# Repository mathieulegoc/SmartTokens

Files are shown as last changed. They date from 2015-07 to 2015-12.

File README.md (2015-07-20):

# SmartTokens
SmartTokens are small-sized tangible tokens that can sense multiple types of motion, multiple types of touch/grip, and send input events wirelessly as state-machine transitions. By providing an open platform for embedding basic sensing capabilities within small form-factors, SmartTokens extend the design space of tangible user interfaces. Here is all the material required to build and use SmartTokens, from PCB production files to code.

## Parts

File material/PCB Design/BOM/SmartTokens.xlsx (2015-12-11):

Designator | Quantity | Description | Supplier 1 | Supplier Part Number 1 | Supplier 2 | Supplier Part Number 2
A1 | 1 | JOHANSON TECHNOLOGY 2450AT18A100E ANTENNA, CERAMIC, 2.45GHZ | Digi-Key | 712-1005-1-ND | Farnell | 1885496
C1, C7 | 2 | 47pF 0402 NP0 50V ±5% | Digi-Key | 445-1243-1-ND | Farnell | 8819670
C2 | 1 | 10uF 0603 X5R 6.3V ±20% | Digi-Key | 478-5318-1-ND | Farnell | 1833804
C3, C4, C5, C8, C9, C10, C14, C16, C18 | 9 | 100nF 0402 X7R 16V ±10% | Digi-Key | 399-3521-1-ND | Farnell | 1288252
C6, C19 | 2 | 10nF 0402 X7R 25V ±5% | Digi-Key | 399-1279-1-ND | Farnell | 1692285
C11, C12 | 2 | 15pF 0402 NP0 50V ±5% | Digi-Key | 399-1014-1-ND | Farnell | 1414577
C13, C15 | 2 | 1uF 0603 X5R 10V ±10% | Digi-Key | 478-1251-1-ND | Farnell | 1759399
C17 | 1 | 10uF 0603 TANTALUM 10V ±20% | Digi-Key | 478-9527-1-ND | Farnell | 2408423
L1 | 1 | MURATA - LQP15MN3N9B02D - 3.9NH ±0.1NH 0402 | Digi-Key | 490-1131-1-ND
L2 | 1 | MURATA - LQP15MN5N1B02D - 5.1NH ±0.1NH 0402 | Digi-Key | 490-6758-1-ND
R1 | 1 | 43K 0402 1/16W ±1% | Digi-Key | 541-43.0KLCT-ND | Farnell | 1358086
R2, R4, R6, R8, R9, R10, R11, R12 | 8 | 10K 0402 1/16W ±1% | Digi-Key | 541-10.0KLCT-ND | Farnell | 2072517
R5 | 1 | 100K 0402 1/16W ±1% | Digi-Key | 541-100KLCT-ND | Farnell | 2072519
U1 | 1 | NXP JN5168 IEEE802.15.4 Wireless Microcontroller | Digi-Key | 568-10145-1-ND | Farnell | 2341782
U2 | 1 | STMicroelectronics 150 mA ultra low quiescent current linear voltage regulator | Digi-Key | 497-10530-1-ND | Farnell | 2311337
U4 | 1 | Atmel AT42QT1070 Seven-channel QTouch® Touch Sensor IC | Digi-Key | AT42QT1070-MMHCT-ND
U5 | 1 | STMicroelectronics LSM6DS0 iNEMO inertial module | Digi-Key | 497-14855-1-ND | Farnell | 2462797
Y1 | 1 | EPSON - TSX-3225, 32MHZ, 10PPM, 9PF - CRYSTAL, TSX-3225, 32MHZ, 10PPM, 9PF |  |  | Farnell | 1712845

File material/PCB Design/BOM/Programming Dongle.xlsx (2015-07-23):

Designator | Quantity | Comment | Description | Supplier 1 | Supplier Part Number 1
C1 | 1 | 10uF 0603 X5R 6.3V AVX | AVX - 06036D106MAT2A - 0603 X5R 6.3V 10UF | Farnell | 1833804
C2 | 1 | 1uF 0603 X5R 10V MULTICOMP | MULTICOMP - MC0603X105K100CT - MLCC 0603 X5R 10V 1UF | Farnell | 1759399
C3, C4, C5, C7 | 4 | 100nF 0402 X7R 16V ±10% | 100nF 0402 X7R 16V ±10% | Farnell | 1288252
C6 | 1 | 4.7uF 0603 X5R 10V KEMET | KEMET - C0603C475K8PACTU - CONDENSATEUR 4.7UF 10V X5R 0603 | Farnell | 1572625
C8 | 1 | 10nF 0402 X7R 25V KEMET | KEMET - C0402C103J3RACTU - MLCC 0402 25V 0.01UF | Farnell | 1692285
C9, C10 | 2 | 47pF 0402 NP0 50V MURATA | MURATA - GRM1555C1H470JZ01D - 0402 47PF 50V | Farnell | 8819670
D1 | 1 | OVS-0604 | MULTICOMP - OVS-0604 - LED, 0603, GREEN, 300MCD, 520NM | Farnell | 1716771
D2 | 1 | RGB LED PLCC | MULTICOMP - 703-1028 - LED RGB 3528 PLCC | Farnell | 2112143
D3, D4 | 2 | Schottky barrier single diode | NXP - 1PS76SB10 | Farnell | 1081179
FE1 | 1 | MURATA - BLM18PG471SN1D | Ferrite Bead (470R ~ 100MHz) | Farnell | 1515745
J1 | 1 | MICRO USB B | MOLEX - 47346-0001 - FEMALE MICRO USB B BOTTOM MOUNT | Farnell | 1568026
P1 | 1 | FTSH-104-04-F-DH | Samtec FTSH 4x2 .050" Horizontal SMD
R1 | 1 | 180R 0402 1% VISHAY | VISHAY DRALORIC - CRCW0402180RFKED - 0402 180R 1% | Farnell | 2140698
R2, R3 | 2 | 180R 0402 1/16W ±1% | 180R 0402 1/16W ±1% | Farnell | 2140698
U1 | 1 | ADP3333ARMZ-3.3-R7 | High Accuracy Ultralow IQ, 300 mA, anyCAP Low Dropout Regulator, 2.6 to 12 V Vin, 3.3 V Vout, Industrial, 8-pin SOP (RM-8), Reel | Digi-Key | ADP3333ARMZ-3.3-R7TR-ND
U2 | 1 | FT232RL | USB UART Asynchronous Serial Data Transfer Chip, SSOP-28, Tape and Reel | Farnell | 1146032

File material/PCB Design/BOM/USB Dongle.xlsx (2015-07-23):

Designator | Quantity | Comment | Description | Supplier 1 | Supplier Part Number 1
A1 | 1 | 2450AT18A100 | JOHANSON TECHNOLOGY 2450AT18A100E ANTENNA, CERAMIC, 2.45GHZ | Farnell | 1885496
C1 | 1 | 10uF 0603 X5R 6.3V AVX | AVX - 06036D106MAT2A - 0603 X5R 6.3V 10UF | Farnell | 1833804
C2, C3, C5, C6, C13, C14, C15, C18, C19, C20 | 10 | 100nF 0402 X7R 16V ±10% | 100nF 0402 X7R 16V ±10% | Farnell | 1288252
C4 | 1 | 1uF 0603 X5R 10V MULTICOMP | MULTICOMP - MC0603X105K100CT - MLCC 0603 X5R 10V 1UF | Farnell | 1759399
C7 | 1 | 4.7uF 0603 X5R 10V KEMET | KEMET - C0603C475K8PACTU - CONDENSATEUR 4.7UF 10V X5R 0603 | Farnell | 1572625
C8 | 1 | 10nF 0402 X7R 25V KEMET | KEMET - C0402C103J3RACTU - MLCC 0402 25V 0.01UF | Farnell | 1692285
C9, C10 | 2 | 47pF 0402 NP0 50V MURATA | MURATA - GRM1555C1H470JZ01D - 0402 47PF 50V | Farnell | 8819670
C11, C17 | 2 | 47pF 0402 NP0 50V ±5% | 47pF 0402 NP0 50V ±5% | Farnell | 8819670
C12 | 1 | 10uF 0603 X5R 6.3V ±20% | 10uF 0603 X5R 6.3V ±20% | Farnell | 1833804
C16 | 1 | 10nF | 10nF 0402 X7R 25V ±5% | Farnell | 1692285
C21, C22 | 2 | 15pF 0402 NP0 50V ±5% | 15pF 0402 NP0 50V ±5% | Farnell | 1414577
D1 | 1 | OVS-0604 | MULTICOMP - OVS-0604 - LED, 0603, GREEN, 300MCD, 520NM | Farnell | 1716771
D2 | 1 | RGB LED PLCC | MULTICOMP - 703-1028 - LED RGB 3528 PLCC | Farnell | 2112143
D3 | 1 | OVS-0603 | MULTICOMP - OVS-0603 - LED 0603 SUPER BRIGHT BLUE | Farnell | 1716770
D4, D5 | 2 | Schottky barrier single diode | NXP - 1PS76SB10 | Farnell | 1081179
FE1 | 1 | MURATA - BLM18PG471SN1D | Ferrite Bead (470R ~ 100MHz) | Farnell | 1515745
J1 | 1 | MICRO USB B | MOLEX - 47346-0001 - FEMALE MICRO USB B BOTTOM MOUNT | Farnell | 1568026
L1 | 1 | 3.9NH 0402 MURATA | MURATA - LQP15MN3N9B02D - 3.9NH ±0.1NH 0402 | Digi-Key | 490-1131-1-ND
L2 | 1 | 5.1NH 0402 MURATA | MURATA - LQP15MN5N1B02D - 5.1NH ±0.1NH 0402 | Digi-Key | 490-6758-1-ND
R1 | 1 | 180R 0402 1% VISHAY | VISHAY DRALORIC - CRCW0402180RFKED - 0402 180R 1% | Farnell | 2140698
R2, R3, R4 | 3 | 180R 0402 1/16W ±1% | 180R 0402 1/16W ±1% | Farnell | 2140698
R5 | 1 | 43K 0402 1/16W ±1% | 43K 0402 1/16W ±1% | Farnell | 1358086
U1 | 1 | ADP3333ARMZ-3.3-R7 | High Accuracy Ultralow IQ, 300 mA, anyCAP Low Dropout Regulator, 2.6 to 12 V Vin, 3.3 V Vout, Industrial, 8-pin SOP (RM-8), Reel | Digi-Key | ADP3333ARMZ-3.3-R7TR-ND
U2 | 1 | FT232RL | USB UART Asynchronous Serial Data Transfer Chip, SSOP-28, Tape and Reel | Farnell | 1146032
U3 | 1 | JN516X | IEEE802.15.4 Wireless Microcontroller | Farnell | 2341782
Y1 | 1 | TSX-3225 | EPSON - TSX-3225, 32MHZ, 10PPM, 9PF - CRYSTAL, TSX-3225, 32MHZ, 10PPM, 9PF | Farnell | 1712845

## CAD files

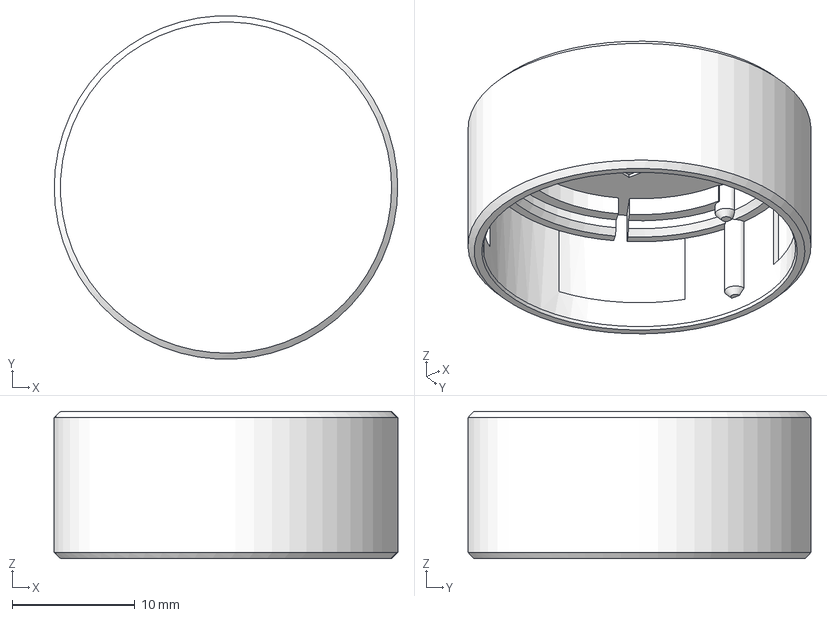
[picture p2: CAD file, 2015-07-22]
material/Shell Design/Step Files/top.stp
28.0 x 28.0 x 12.0 mm

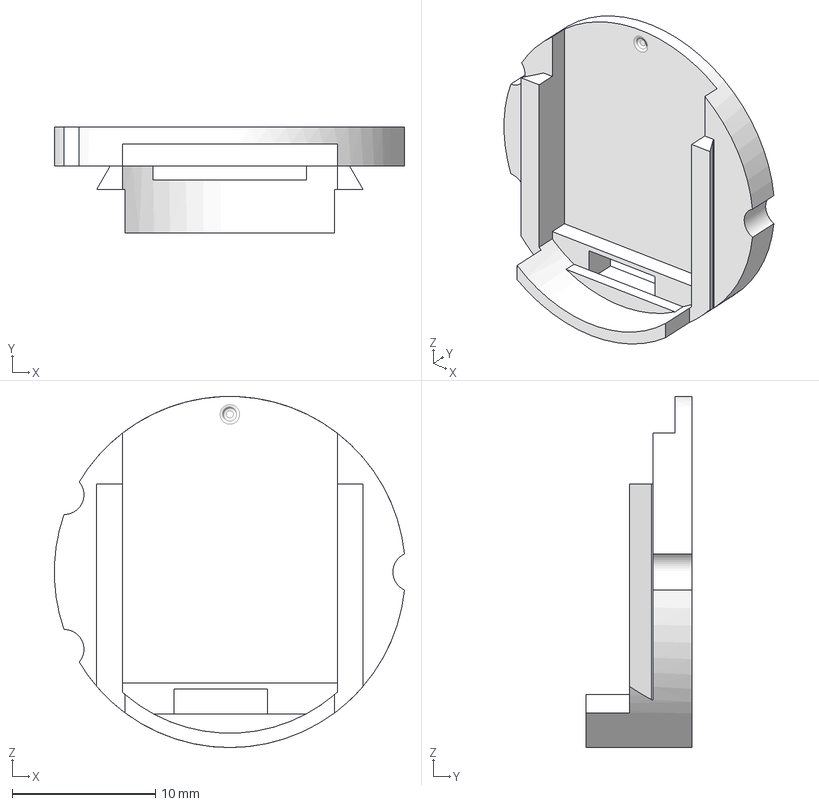
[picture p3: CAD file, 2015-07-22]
material/Shell Design/Step Files/bottom2_2.stp
24.4 x 7.38 x 24.5 mm

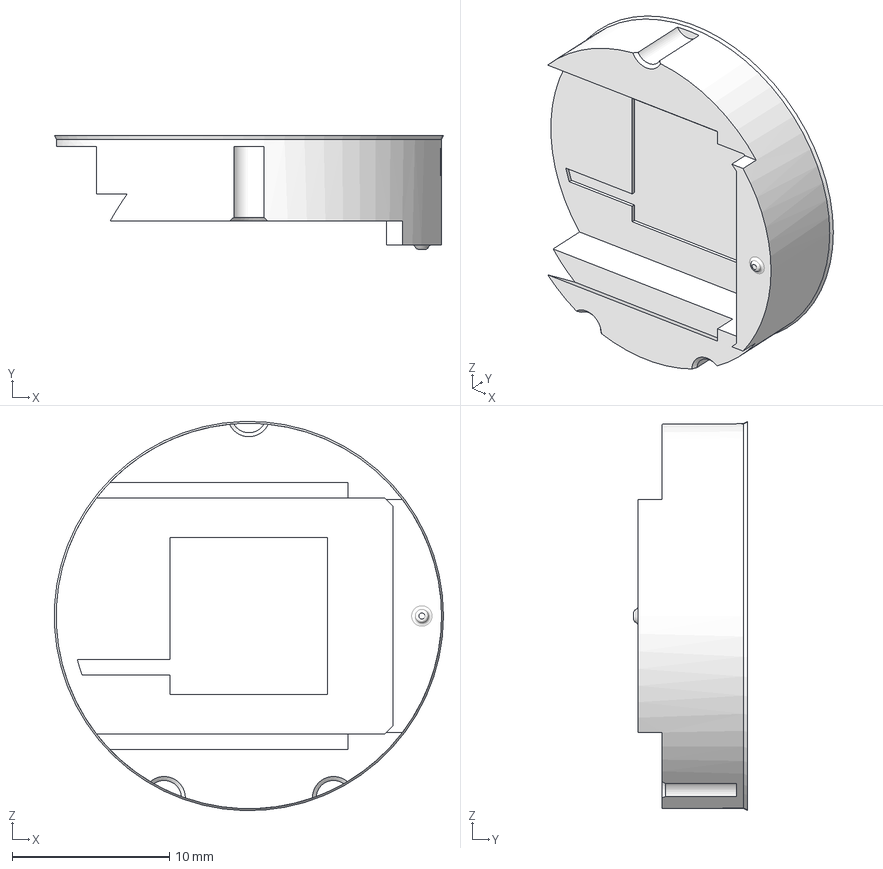
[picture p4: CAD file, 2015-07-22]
material/Shell Design/Step Files/bottom1_2.stp
24.7 x 7.25 x 24.7 mm

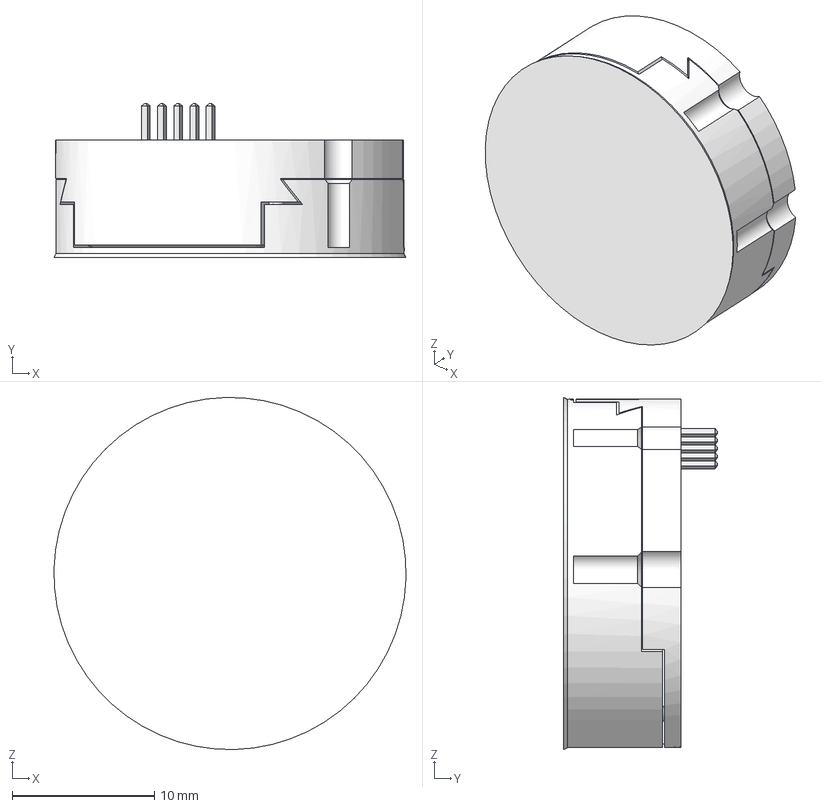
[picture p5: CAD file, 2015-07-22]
material/Shell Design/Step Files/battery_block.stp
24.7 x 10.8 x 24.7 mm
battery
bottom2_2
bottom1_2
battery_connector

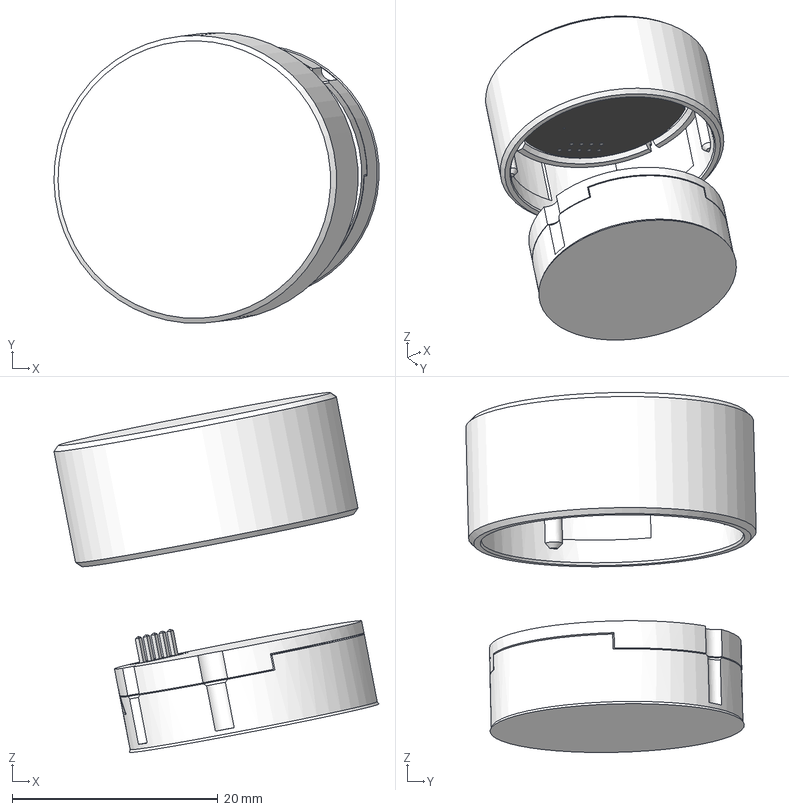
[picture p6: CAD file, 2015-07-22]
material/Shell Design/Step Files/smart_token.stp
31.6 x 28.2 x 35.0 mm
top
pcb
battery
bottom2_2
bottom1_2
battery_connector

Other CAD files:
material/Shell Design/Inventor Files/battery.ipt
material/Shell Design/Inventor Files/battery_block.iam
material/Shell Design/Inventor Files/battery_connector.ipt
material/Shell Design/Inventor Files/bottom1_2.ipt
material/Shell Design/Inventor Files/bottom2_2.ipt
material/Shell Design/Inventor Files/pcb.ipt
material/Shell Design/Inventor Files/smart_token.iam
material/Shell Design/Inventor Files/top.ipt
material/Shell Design/STL files/bottom1_2.stl
material/Shell Design/STL files/bottom2_2.stl
material/Shell Design/STL files/top.stl

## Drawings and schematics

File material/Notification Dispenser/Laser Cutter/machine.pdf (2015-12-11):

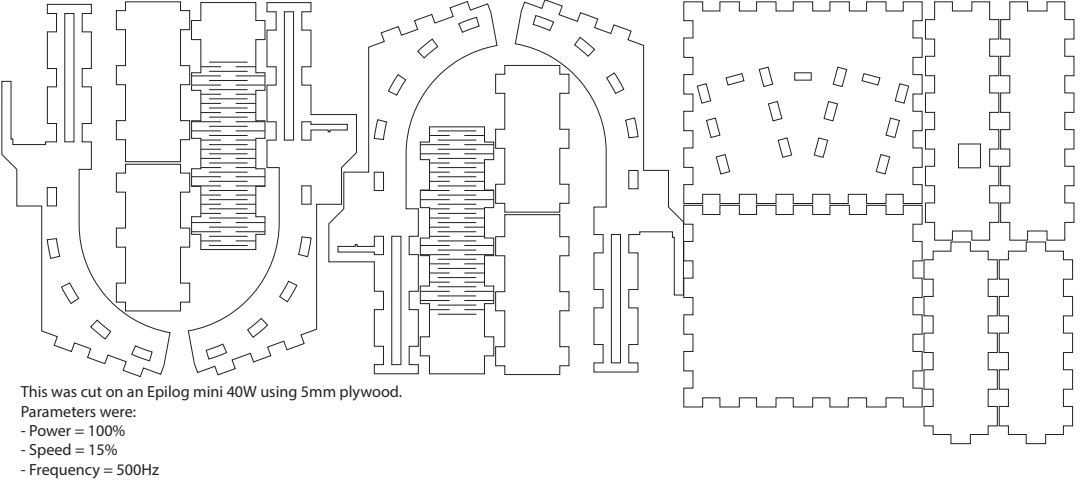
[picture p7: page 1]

This was cut on an Epilog mini 40W using 5mm plywood.
Parameters were:
- Power = 100%
- Speed = 15%
- Frequency = 500Hz

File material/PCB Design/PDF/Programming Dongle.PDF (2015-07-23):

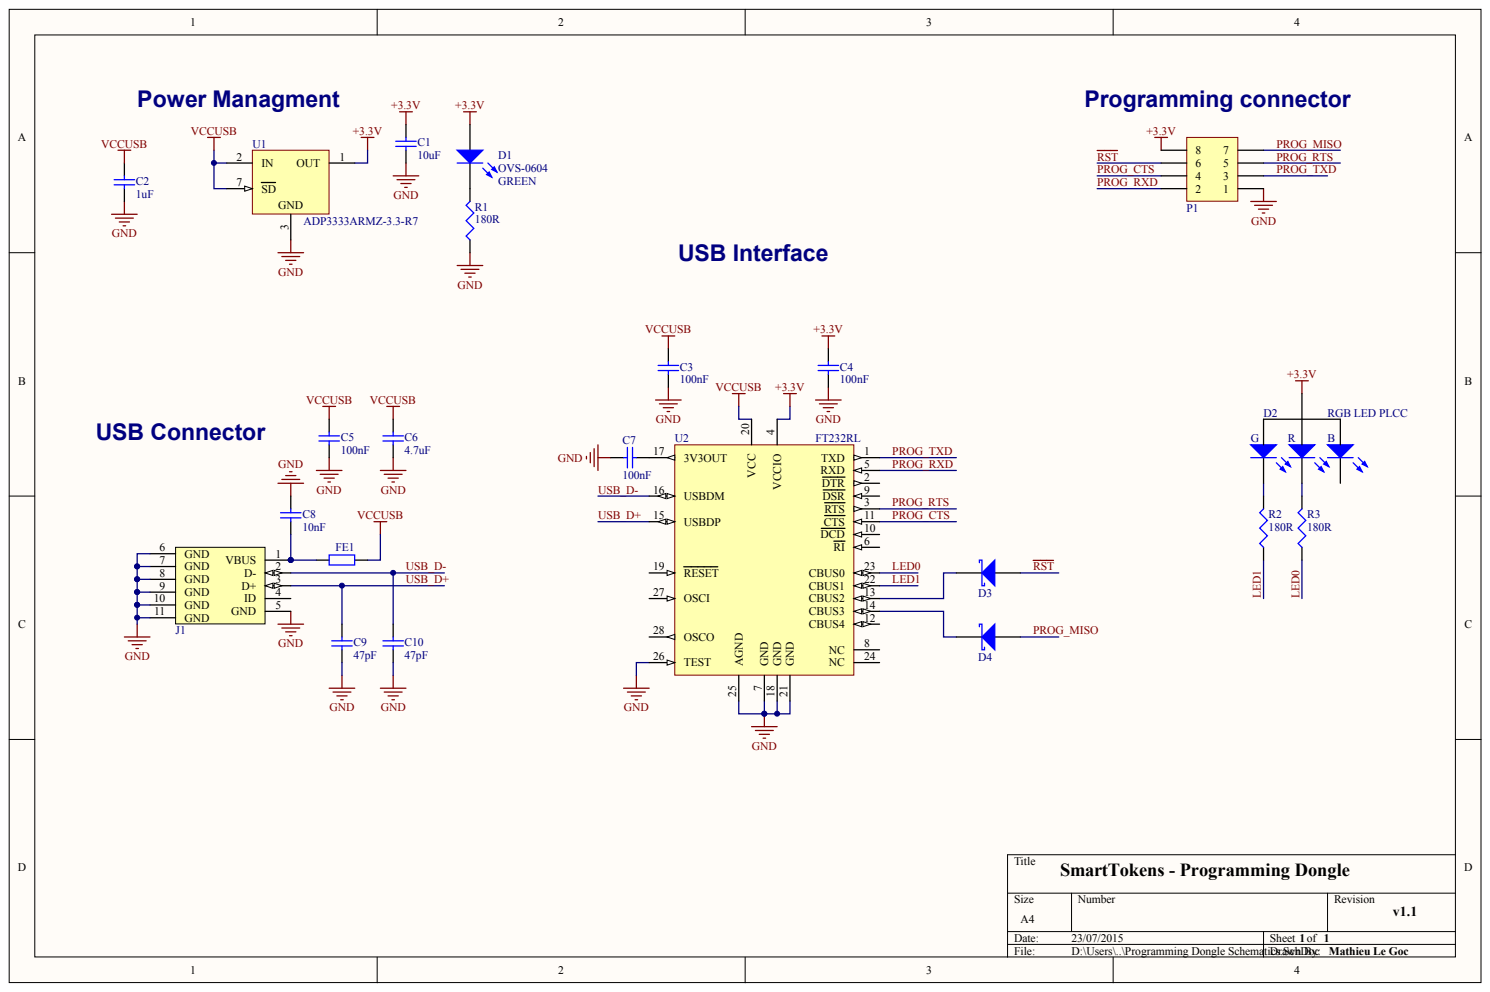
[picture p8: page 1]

OSCI 27 | LED1

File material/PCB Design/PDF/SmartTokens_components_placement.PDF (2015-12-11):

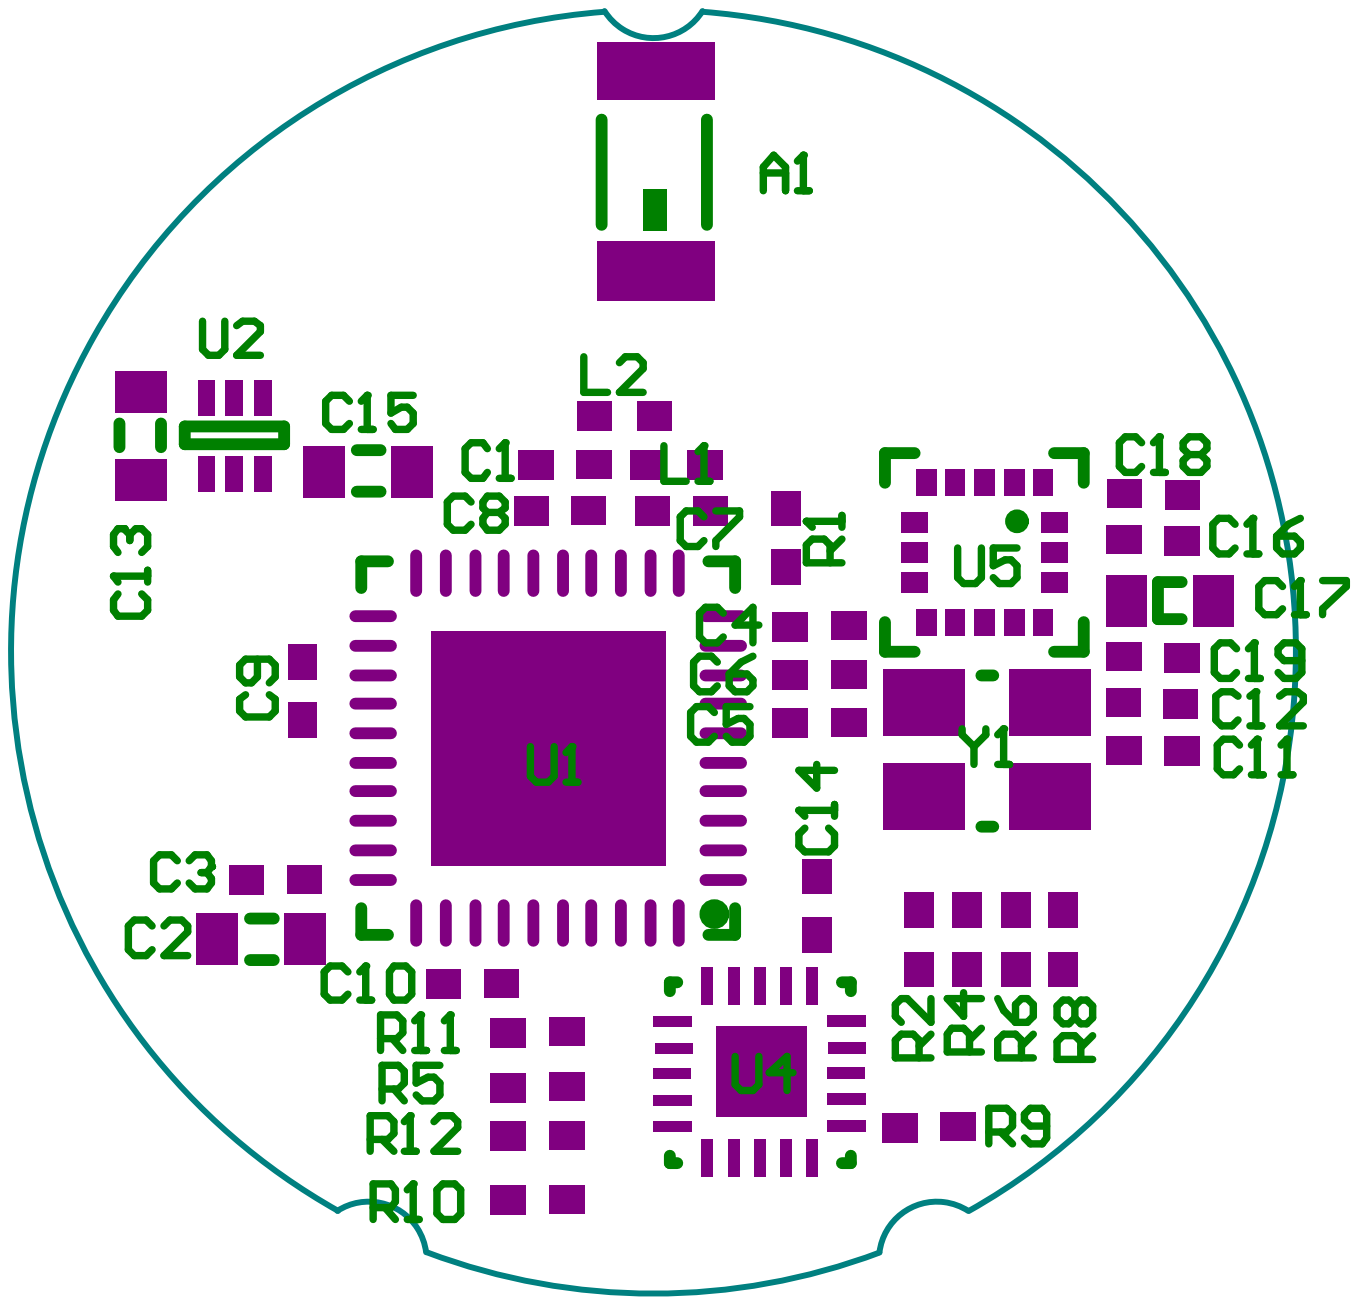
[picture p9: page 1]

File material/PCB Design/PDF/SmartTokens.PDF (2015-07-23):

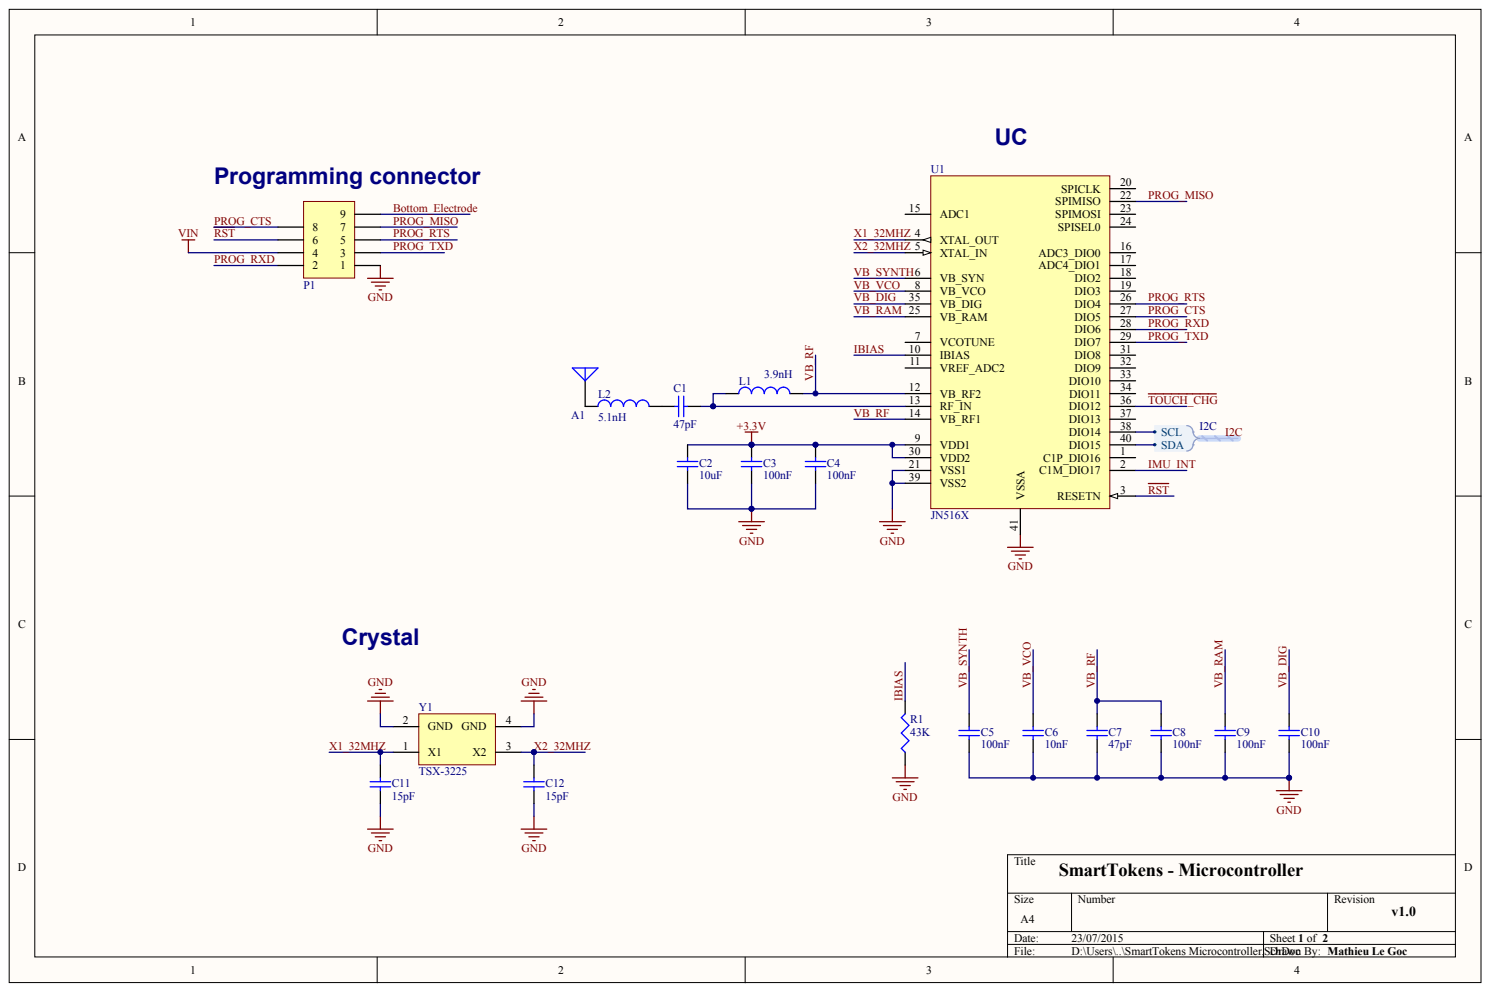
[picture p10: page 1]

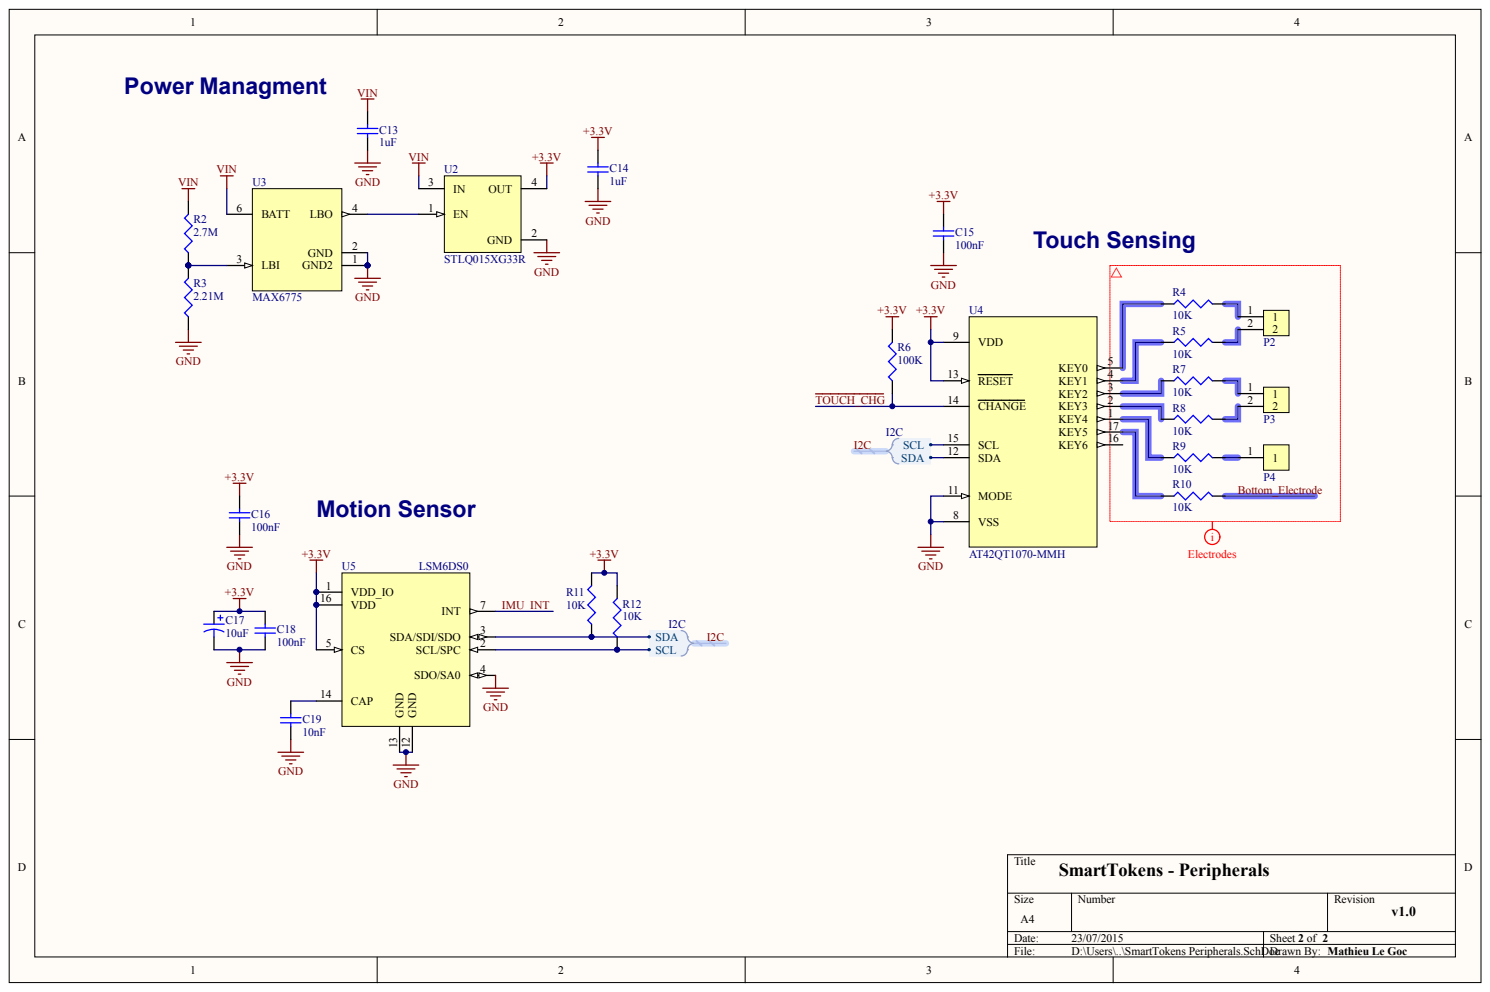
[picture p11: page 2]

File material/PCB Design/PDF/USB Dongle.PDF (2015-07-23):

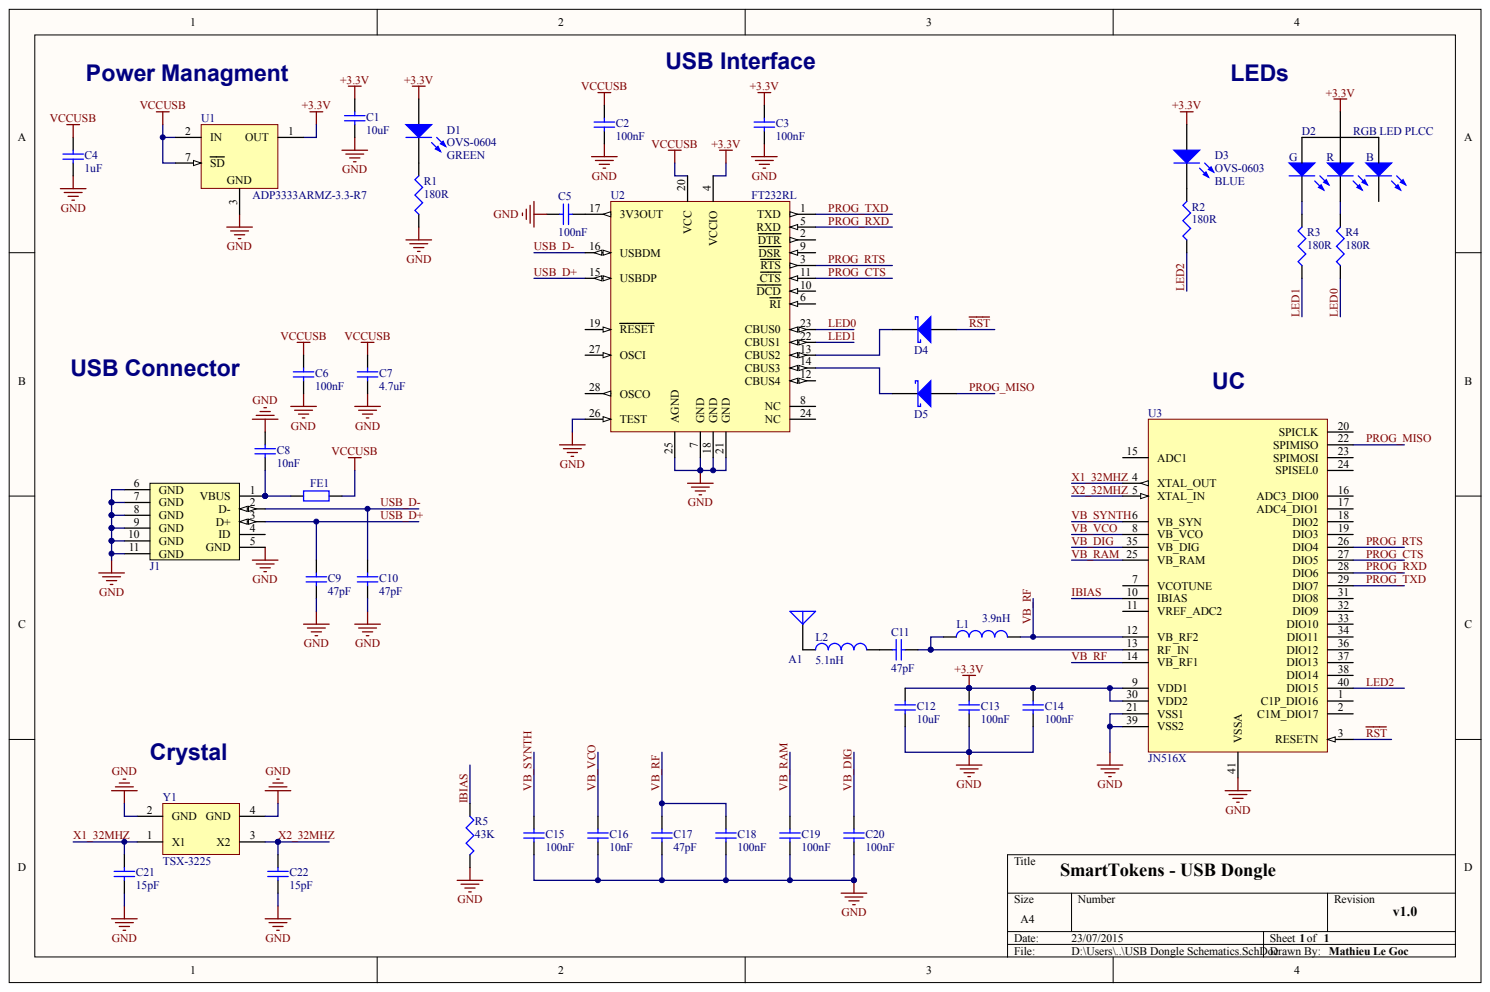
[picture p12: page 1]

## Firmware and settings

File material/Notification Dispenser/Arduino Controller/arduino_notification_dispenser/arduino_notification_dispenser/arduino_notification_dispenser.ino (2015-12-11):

#include <Servo.h>

#define NB_CATEGORIES 3

const int buttonPin = 10;
const int ledPin =  13;

Servo servo[3];
int buttonState = 0;
byte servoAngle[] = {65, 64, 68}; //pour #2 70; avec delta=10 et delay=90
boolean running = false;

void setup()
{
  Serial.begin(9600);
  for (int i = 0; i < NB_CATEGORIES; i++) {
    servo[i].attach(9 + i);
    servo[i].write(servoAngle[i]);
  }
  pinMode(ledPin, OUTPUT);
  pinMode(buttonPin, INPUT);
  digitalWrite(ledPin, LOW);
}

void dropToken(byte id) {
  servo[id].write(servoAngle[id] - 8);
  delay(60); //delay(80);
  //  if(id==2){
  //        servo[id].write(servoAngle[id]-8);
  //   delay(60); //delay(80);
  //  }
  //  else{
  //    servo[id].write(servoAngle[id]-8);
  //    delay(60);
  //  }
  servo[id].write(servoAngle[id]);
  delay(250);
}

void loop()
{
  byte id = 0;
  if (Serial.available()) {
    id = Serial.read() - 1;
    if (id < NB_CATEGORIES)
      dropToken(id);
  }
}

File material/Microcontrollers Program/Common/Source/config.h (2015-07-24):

/*****************************************************************************
 *
 * MODULE:              config.h
 *
 * COMPONENT:           config.h,v
 *
 * VERSION:
 *
 * REVISION:            1.2
 *
 * DATED:               2006/09/07 14:23:55
 *
 * STATUS:              Exp
 *
 * AUTHOR:
 *
 * DESCRIPTION:
 *
 * LAST MODIFIED BY:
 *                      $Modtime: $
 *
 ****************************************************************************
 *
 * This software is owned by Jennic and/or its supplier and is protected
 * under applicable copyright laws. All rights are reserved. We grant You,
 * and any third parties, a license to use this software solely and
 * exclusively on Jennic products. You, and any third parties must reproduce
 * the copyright and warranty notice and any other legend of ownership on each
 * copy or partial copy of the software.
 *
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
 * Copyright Jennic Ltd 2009. All rights reserved
 *
 ****************************************************************************/

#ifndef  CONFIG_H_INCLUDED
#define  CONFIG_H_INCLUDED

#if defined __cplusplus
extern "C"
{
#endif

/****************************************************************************/
/***        Include Files                                                 ***/
/****************************************************************************/
#include <jendefs.h>

/****************************************************************************/
/***        Macro Definitions                                             ***/
/****************************************************************************/
#define DBG_ENABLE

/* Network parameters */
#define PAN_ID                      0xCAFE
#define COORDINATOR_ADR             0x0000
#define END_DEVICE_START_ADR        0x0001
#define MAX_END_DEVICES             100

/* Defines the channels to scan. Each bit represents one channel. All channels
 in the channels (11-26) in the 2.4GHz band are scanned. */
#define SCAN_CHANNELS               0x07FFF800UL
#define CHANNEL_MIN                 11

/* Duration (ms) = 15.36ms x (2^ACTIVE_SCAN_DURATION + 1) */
#define ACTIVE_SCAN_DURATION        3
/* Duration (ms) = 15.36ms x (2^ENERGY_SCAN_DURATION + 1) */
#define ENERGY_SCAN_DURATION        3

/* Custom macros */
#define ON							TRUE
#define OFF							FALSE
#define false						FALSE
#define true						TRUE

/* Messages types */
#define DBG 							0
#define IMU_RAW_DATA 					1
#define ACCEL_RAW_DATA 					2
#define GYRO_RAW_DATA 					3
#define TOUCH_RAW_DATA 					8
#define STATUS_DATA						9
#define ROBOT_MOTORS_VALUES				7
#define TIME_DATA						8

#define DATA_TO_STREAM					0xF
#define STREAM_IMU						0xA
#define STREAM_TOUCH					0xB
#define STREAM_STATUS					0xC
#define STREAM_ACCEL					0xD
#define STREAM_GYRO						0xE
#define STREAM_TIMESTAMP				0x9

#define ASK_FOR_DATA					0xAA
#define SET_TIMESTAMP					0xAB
#define ASK_FOR_TIMESTAMP				0xAC
#define MEASURE_TIME_OF_FLIGHT			0xAD
#define MESSAGE_SIZE					0x02

/* Debug flags */
#ifdef DBG_ENABLE
#define DEBUG_EXCEPTION							TRUE
#define DEBUG_INCOMING							TRUE
#define DEBUG_DEVICE_FUNC					    TRUE
#define DEBUG_DEVICE_VARS					    TRUE
#define DEBUG_DEVICE_SENSOR						TRUE
#define DEBUG_DEVICE_INT						TRUE
#define DEBUG_DEVICE_CONFIG						TRUE
#define DEBUG_CBUFFER							FALSE
#define DEBUG_STATE_MACHINE						TRUE

#else
#define DEBUG_EXCEPTION							FALSE
#define DEBUG_DEVICE_FUNC					    FALSE
#define DEBUG_INCOMING							FALSE
#define DEBUG_DEVICE_VARS					    FALSE
#define DEBUG_DEVICE_SENSOR						FALSE
#define DEBUG_DEVICE_INT						FALSE
#define DEBUG_DEVICE_CONFIG						FALSE
#define DEBUG_CBUFFER							FALSE
#define DEBUG_STATE_MACHINE						FALSE
#endif

/****************************************************************************/
/***        Pins Definitions                                             ***/
/****************************************************************************/
#define ROBOT_TOUCH_CHANGE 	1<<12
#define ROBOT_IMU_INT		1<<17
#define DONGLE_STATUS_LED	1<<15

/****************************************************************************/
/***        Type Definitions                                              ***/
/****************************************************************************/
typedef uint8 State;
typedef uint8 Transition;
typedef uint8 Transition;
typedef uint8 Grip;

typedef struct Message
{
	uint8 message_id;
	uint8 message_size;
	uint16 payload[7];
} Message;

typedef struct
{
	int16 ax;
	int16 ay;
	int16 az;
	int16 gx;
	int16 gy;
	int16 gz;
} ImuRawData;

typedef struct
{
	int16 idx;
	int16 ax;
	int16 ay;
	int16 az;
} AccelRawData;

typedef struct
{
	int16 gx;
	int16 gy;
	int16 gz;
} GyroRawData;

typedef struct
{
	int16 iAx;
	int16 iAy;
	int16 iAz;
	int16 iGx;
	int16 iGy;
	int16 iGz;
} ImuIntegrals;

typedef struct
{
	Transition transition;
	Grip grip;
} StatusData;

typedef struct
{
	State currentState;
	State previousState;
} ManipulationState;
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

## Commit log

2015-07-22 Added 3D CAD files
    [battery.ipt, battery_block.iam, battery_block.stp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]
2015-07-23 Added electronics design files
    [Programming Dongle PCB.GBL, Programming Dongle PCB.GBO, Programming Dongle PCB.GBP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]
2015-12-11 Revision 2
    Added the hardware V2
    [Programming Dongle PCB.GBL, Programming Dongle PCB.GBO, Programming Dongle PCB.GBP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]
